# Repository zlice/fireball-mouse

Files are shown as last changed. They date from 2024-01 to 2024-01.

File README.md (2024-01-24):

# Fireball mouse

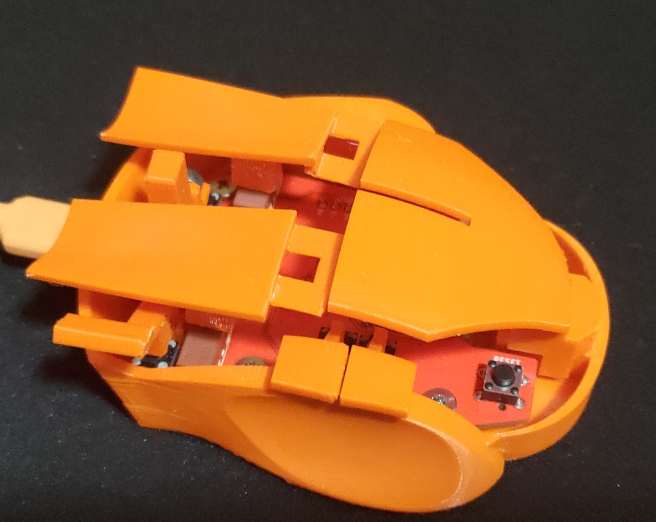
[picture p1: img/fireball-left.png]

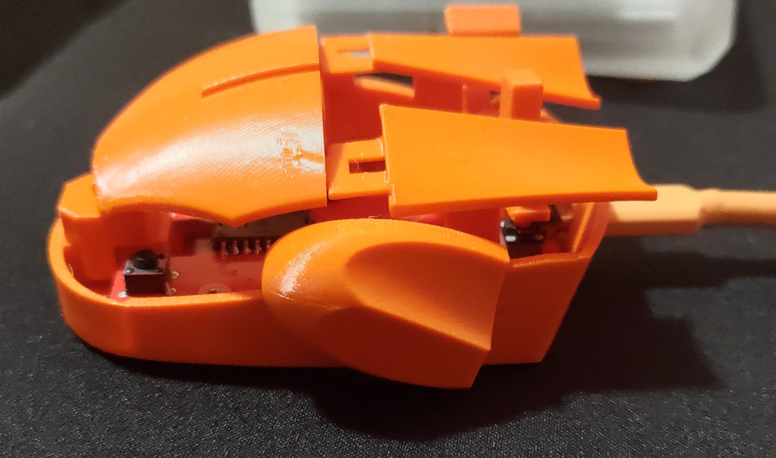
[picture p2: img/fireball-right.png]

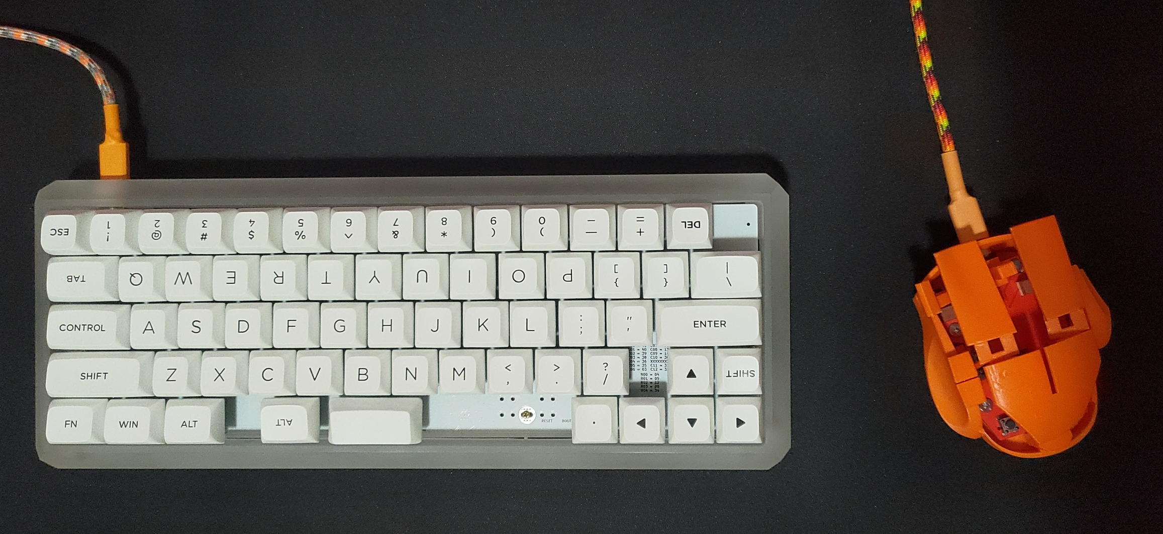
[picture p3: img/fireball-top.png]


Small PMW3360 fingertip mouse with a magnetic hall sensor joystick for scrolling and single 'fire' button for enter.

Designed for Kailh Mute silent switches (the small 6-7mm box ones) and regular sized mouse switches for left/right click (12-13mm x 5-6mm). Bottom is designed for 4 feet with mounting screws near the back middle for the top shell. The top shell is open for minimal hand contact and weight reduction with no 'middleman' shell.

# Building / Parts

### Part List

 - PWM3360 (desolder from donor or grab some off aliexpress)
 - Kailh Quiet Mute Micro Switches (https://www.kailhswitch.com/micro-switches/mouse-micro-switches/quiet-mute-micro-switches.html - aliexpress or elsewhere)
 - USB4085-GF-A (digikey or newark if out of stock on jlcpcb)
 - M3 0.5x4mm screws (PCB and shell mounting - https://www.amazon.com/gp/product/B0C1SGKGWZ)
 - M3 16mm socket screws (for joystick mount - https://www.amazon.com/gp/product/B07PZ3XXPF)
 - N50 magnets 4x1mm cylinder (aliexpress, alibaba, kj magnets)
 - ABS or PC+PBT 3D printing filament (PushPlastic PBT is what I used for my final version. Spool is not compatible with Bambu AMS btw :])
 - Huano Yellow Dot switches (aliexpress, almost linear if not directly 90 degrees of force - optional)
 - TS02-66-50-BK-160-SCR-D (digikey or newark, small 6mm switch for reset/boot - optional)

### Building

May need tweaking for every printer and filament combo. The bambu project in the [stl](./stl) directory should give the orientations and settings that I used to print.

**general print guide**

 - 0.16mm layer height
 - print bottom separate
 - print top separate
 - print small pieces and side clicks together
 - print left/right clicks together
 - 33mm/s outer shell and overhangs
 - support on the the right finger grip
 - support on the thumb, USB and bottom+top screw mounts (auto worked for these)
 - 6 bottom layers for the bottom
 - rotations for the fire/flip, joystick and clicks are important! (joystick will likely break from screw force if in wrong orientation)

**cleanup**

 - bottom screw mount supports can be punctured and twisted out
 - bottom left thumb overhang needs sanding after support is removed
 - left/right click contacts can be sanded, washed, and electrical taped. But click contact can be very finicky (especially with 'huano yellow dot' switches, I eventually gave up and opted to use the raw plastic). This was the hardest part of 'feel' to get right. Contacts may need moved left/right if you use a 12mm omron style switch vs a kailh square switch.
 - side (forward/backward) clicks support can be a bit messy if you wait for it to cool. Removing supports while warm was easier for me in general but should be done here since the part is small and is less likely to warp or deform while still warm.
 - fire button, side clicks and joystick mount are press fit: print smaller test fits before or you'll have to rig some electrical tape for loose fits, or sand (or break) parts on tight fits.
 - magnetic joystick will need tape over the USB connector to make sure it doesn't contact it. The hall sensor routes **under** the joystick faces **away** from the joystick magnets. Technically the wrong direction, but it works great for me. Another sensor can be placed on the side but is best suited in a similar location on the other side of the joystick. See [ideal locations here](./img/halls.png). The code for the joystick/scroll-stick has been updated to read 10 times and use a +- margin to auto-adjust values for scroll up+down. Logic or values may need changed if the magnets are in different polarity or the sensors are positioned differently (reading different ranges).
 - magnets may need test fits depending on print tolerances. Mine were snug and required no glue to stay in place which is perfect. Make sure they are centered and in the right positions (north/south).
 - if your joystick is squeaky or doesn't move smoothly, sanding the inside with the screw's threads may help. Sanding the edges of the bottom or where parts may rub can help also.
 - tightening PCB mounts should be done evenly and just enough to work with everything else
 - tightening top mounts should be done evenly and just enough to work with clicks, every mm counts for feel here

The PCB will likely not line up 100% !!! Tolerances can vary and you are not always going to get the exact same thing if you don't pay for high tolerances.

Be sure to test fit anyway because anything may be off slightly and it could matter!

# QMK

### Setup

Copy **this** project's qmk `fireball` directory to **qmk_firmware**'s `ploopy` directory.

```sh
git clone https://github.com/qmk/qmk_firmware.git

cp -r qmk/keyboards/ploopyco/fireball qmk_firmware/keyboards/ploopyco/
```

### Compile

In `qmk_firmware`

```sh
qmk compile -kb ploopyco/fireball -km default
```

### Flash

The first time you connect the RP2040 it should be empty and go into boot mode. Once flashed, pressing 'forward' while connecting to USB will enter boot mode, reset/boot buttons may help with a reconnect and boot if needed.

Mount the RP2040 and copy `qmk_firmware/.build/ploopyco_fireball_default.uf2` to the RP2040.

```sh
sudo mount /dev/sda1 /mnt/usb && sudo cp .build/ploopyco_fireball_default.uf2 && sudo umount /mnt/usb
```

# FreeCAD

The finished parts are meshed and provided in the [stl](./stl) directory.

Most of this was copied from my original version. The left and right finger grips were slightly modified but I didn't bother reinventing them because they worked for years great. A lot of confusing FreeCAD methods that you can do one way but not another were used to get make parts. The 'misc' group are left over parts that may break the child parts, test fittings and wires used to sweep/loft/extrude and create cuts and parts.

# KiCAD / jlcpcb

Exporting gerbers/drills is the same as every project I've seen, however for jlcpcb I found multiple tutorials and they all seemed out of date. I used [wokwi's jlcpcb script](https://github.com/wokwi/kicad-jlcpcb-bom-plugin) to make placement files, but still needed to rotate them when setting the PCB assembly up.

- File > Fabcrication outputs > component placement (to /tmp/fireball-components)
- `./kicad_pos_to_cpl.py /tmp/fireball-components/Fireball-top-pos.csv /tmp/fireball-jlcpcb-placement-pos.cmp.csv`

The [jlcpcb](./jlcpcb) directory should be a good start to upload for boards.

You may need to replace some parts if they are out of stock. I think I had to use a TexasInstrument converter instead of one in the BOM.

You will have to trim the 4-pin USB header or desolder for it to fit properly in the shell. This is more for a backup or if you do not want to use a USB-C connector and want a straight wire from mouse to the PC USB. If you do not want a raw cable connection, I would remove it from BOM or PCB before exporting.

# Improvements

- PMW3360 bottom mount is slightly off for me and could be moved/centered better.
- The extra PMW3360 mount square groove in the middle is probably useless and could be removed.
- Thumb groove could be extended up a bit at a 45 degree angle. Your thumb can touch the 'back' button since you are not always flat. I don't accidentally press it and it is not that noticeable or bothersome, but it could be something to look at.
- Hall sensor placement could be better. If the PCB is redone, it may be better to put 2 sensors on the side or directly in front+behind the joystick if possible.
- Fire/flip/enter and joystick may feel better if a bit taller. Left/Right clicks ended up being higher than expected.
- Left/Right click feel is more precise to adjust than I expected. Part of this is due to the light weight top and back mounting. The double prong mounts that commercial mice use help prevent rocking side-to-side which created a very uneven, unpredictable and bad click feel. If I try again it may be ideal to mount clicks directly under where they connect somehow, or at least separately.
- Add capacitors to hall sensor outputs to smooth out noise

# Shoutouts

- Jfedor for the PCB - https://github.com/jfedor2/rp2040-pmw3360
- QMK for the software/firmware and helpful community
- wokwi for the placement script - https://github.com/wokwi/kicad-jlcpcb-bom-plugin

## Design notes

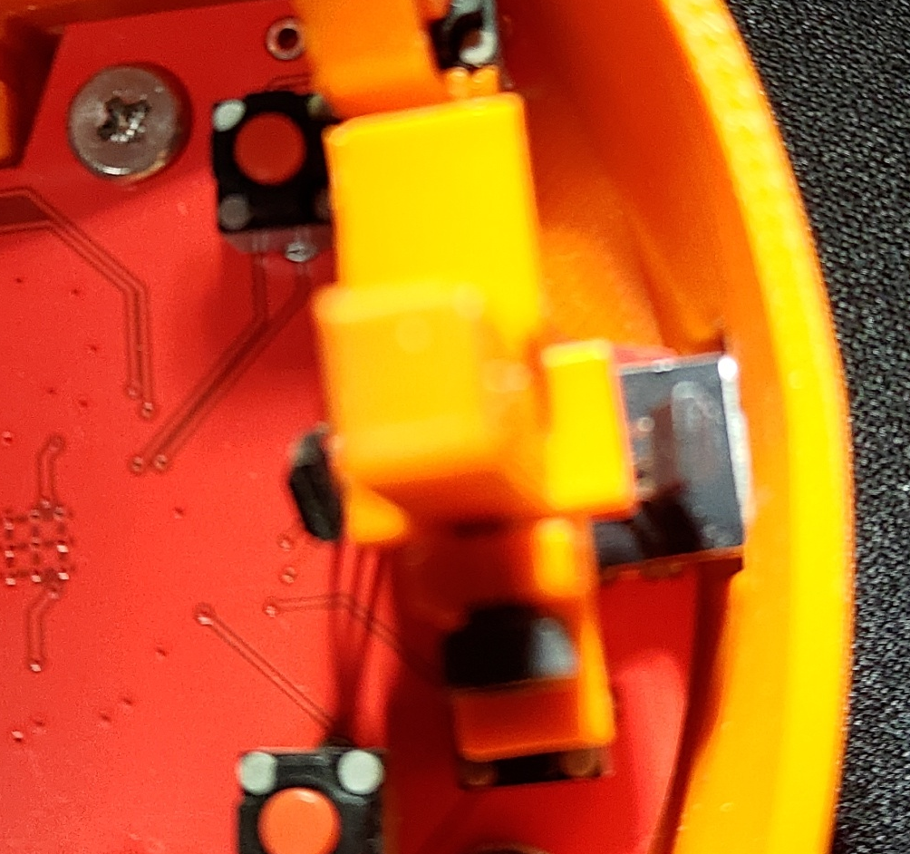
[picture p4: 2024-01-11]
img/halls.png

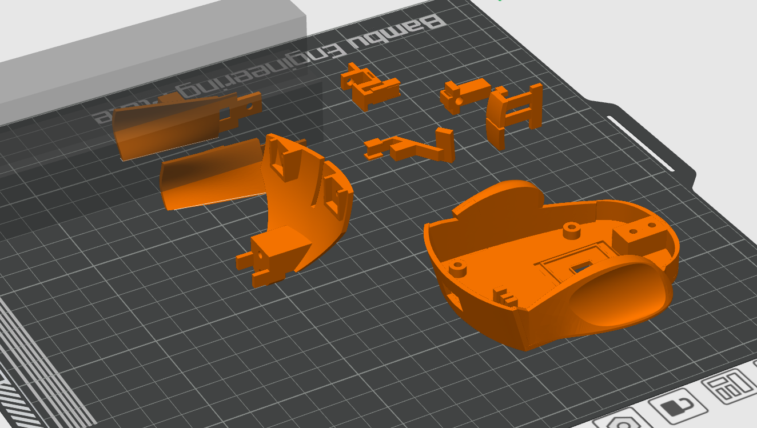
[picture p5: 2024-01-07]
stl/plate1.png

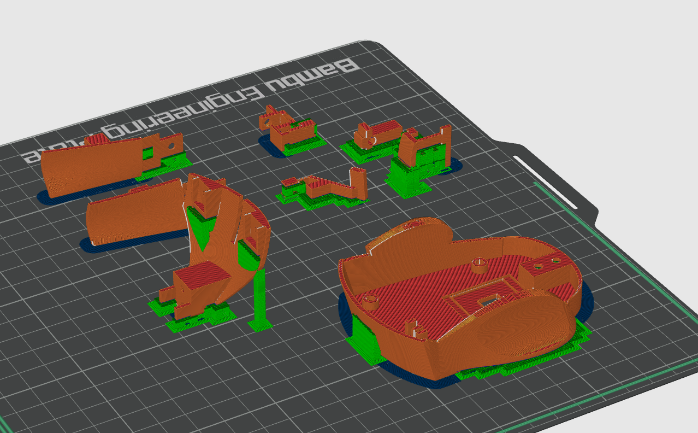
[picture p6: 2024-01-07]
stl/plate2.png

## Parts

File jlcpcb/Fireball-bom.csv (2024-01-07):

Id | Designator | Footprint | Quantity | Designation | Supplier and ref
1 | C18,C19 | C_0402_1005Metric | 2 | 30p | C1570
2 | C17,C2,C8,C6,C5,C7,C4,C1,C3,C9 | C_0402_1005Metric | 10 | 100n | C1525
3 | R6,R7 | R_0402_1005Metric | 2 | 1k | C11702
4 | R5,R2 | R_0402_1005Metric | 2 | 10k | C25744
5 | U3 | RP2040-QFN-56 | 1 | RP2040 | C2040
6 | Y1 | Crystal_SMD_3225-4Pin_3.2x2.5mm | 1 | Crystal_GND24 | C9002
7 | J1 | PinHeader_1x04_P2.54mm_Vertical | 1 | Conn_01x04
8 | C14 | C_0402_1005Metric | 1 | 4.7u | C23733
9 | C10,C16,C15,C13 | C_0402_1005Metric | 4 | 1u | C52923
10 | R4,R3 | R_0402_1005Metric | 2 | 27
11 | U4 | SOT-23-5 | 1 | TLV73333PDBV | C134139
12 | R1 | R_0402_1005Metric | 1 | 39 | C25110
13 | U5 | SOIC-8_5.23x5.23mm_P1.27mm | 1 | W25Q128JVS | C97521
14 | C12 | C_0603_1608Metric | 1 | 1u | C15849
15 | C11 | C_0603_1608Metric | 1 | 0.1u | C14663
16 | U1 | SOT-23-5 | 1 | TCR2EF19

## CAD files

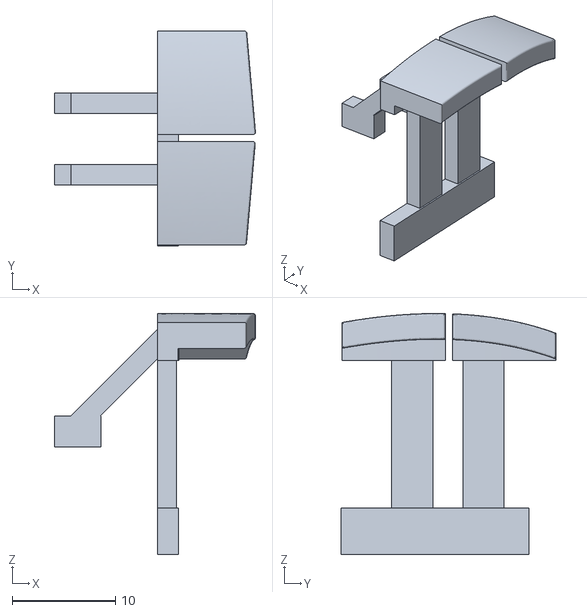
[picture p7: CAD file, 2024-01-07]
stl/side-clk.stl
19.5 x 20.8 x 23.3

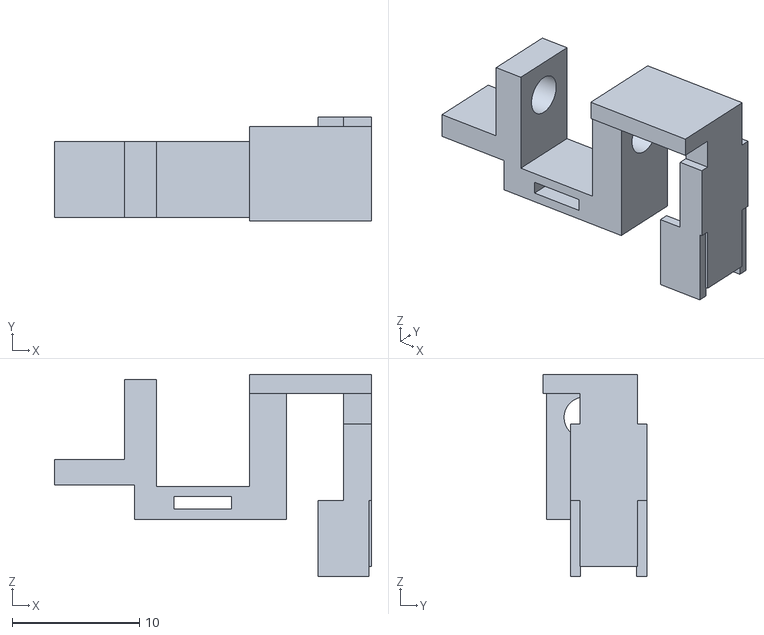
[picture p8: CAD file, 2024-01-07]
stl/js-bot.stl
24.9 x 8.15 x 15.9

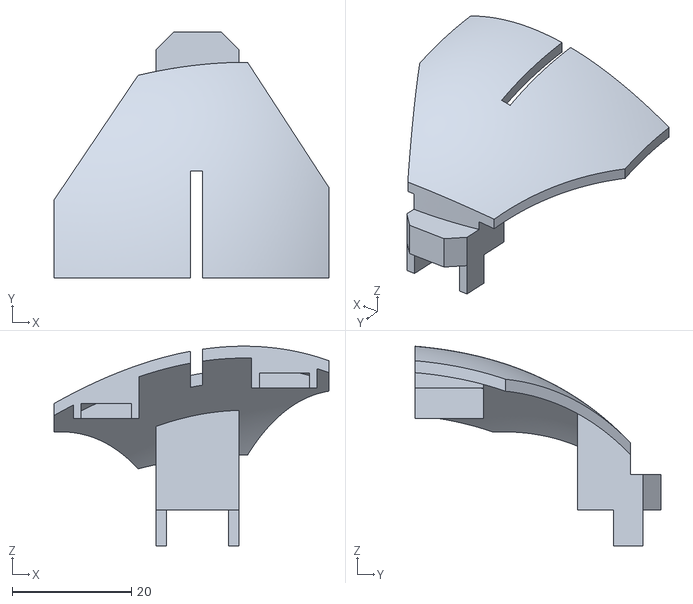
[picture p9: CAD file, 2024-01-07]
stl/top.stl
46.2 x 41.3 x 33.5

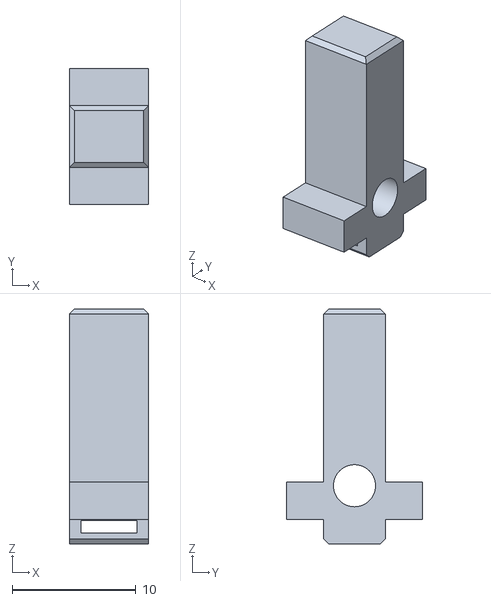
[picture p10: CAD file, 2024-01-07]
stl/js-top.stl
6.40 x 11.0 x 19.0

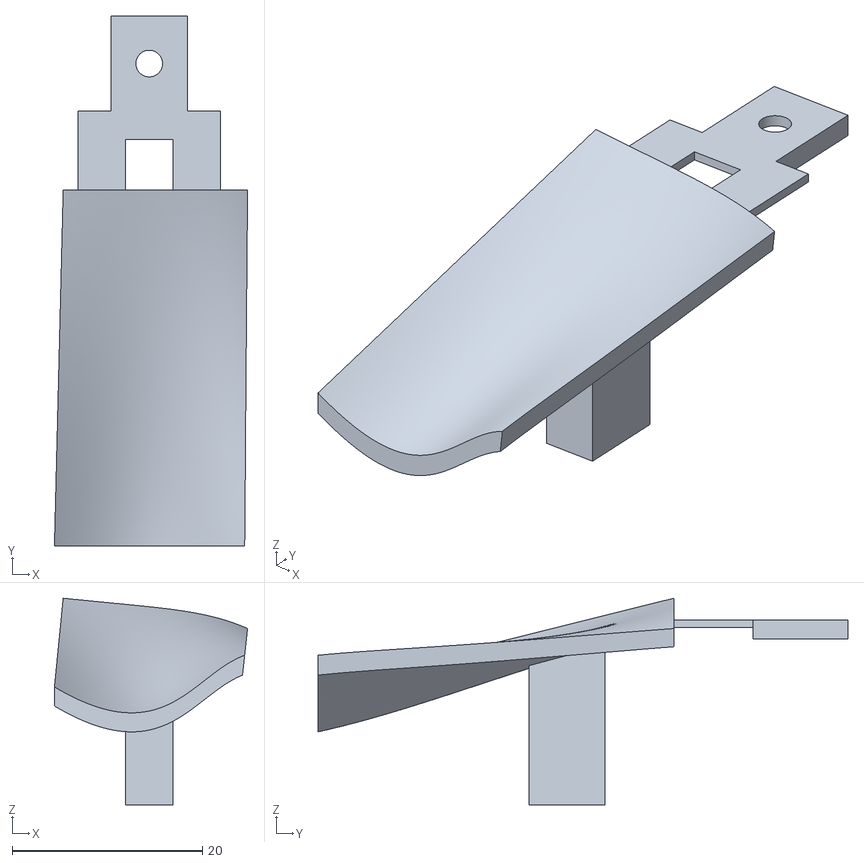
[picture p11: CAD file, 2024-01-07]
stl/lclk.stl
20.3 x 55.7 x 21.7

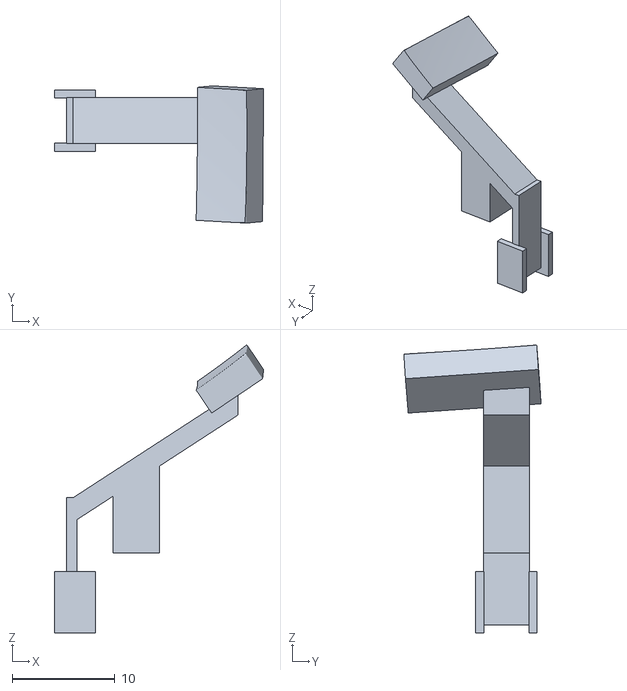
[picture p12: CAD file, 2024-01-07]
stl/flip.stl
20.4 x 13.4 x 28.1

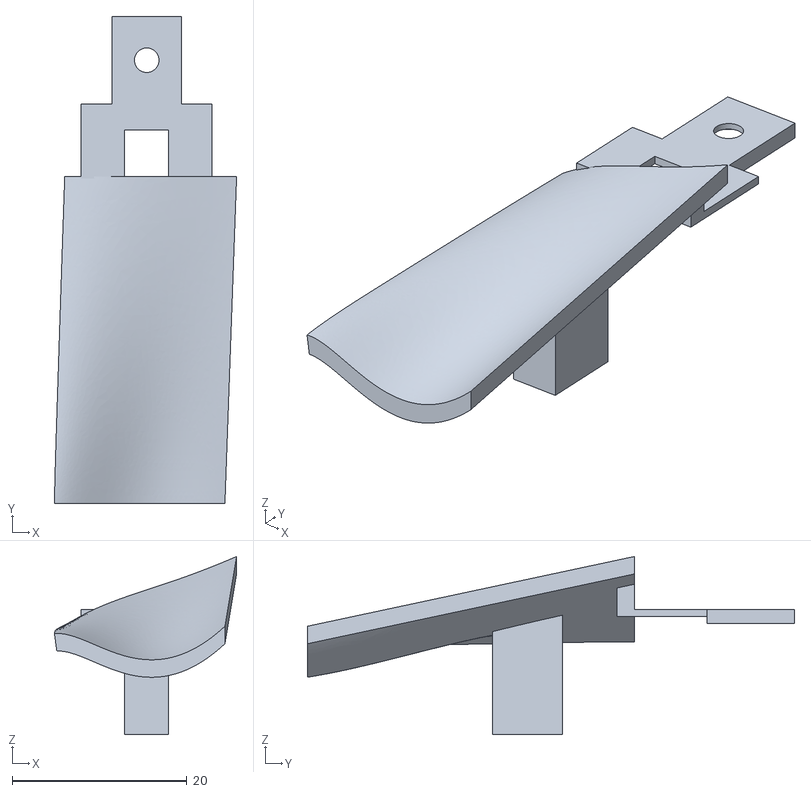
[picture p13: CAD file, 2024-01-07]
stl/rclk.stl
20.8 x 55.7 x 20.4

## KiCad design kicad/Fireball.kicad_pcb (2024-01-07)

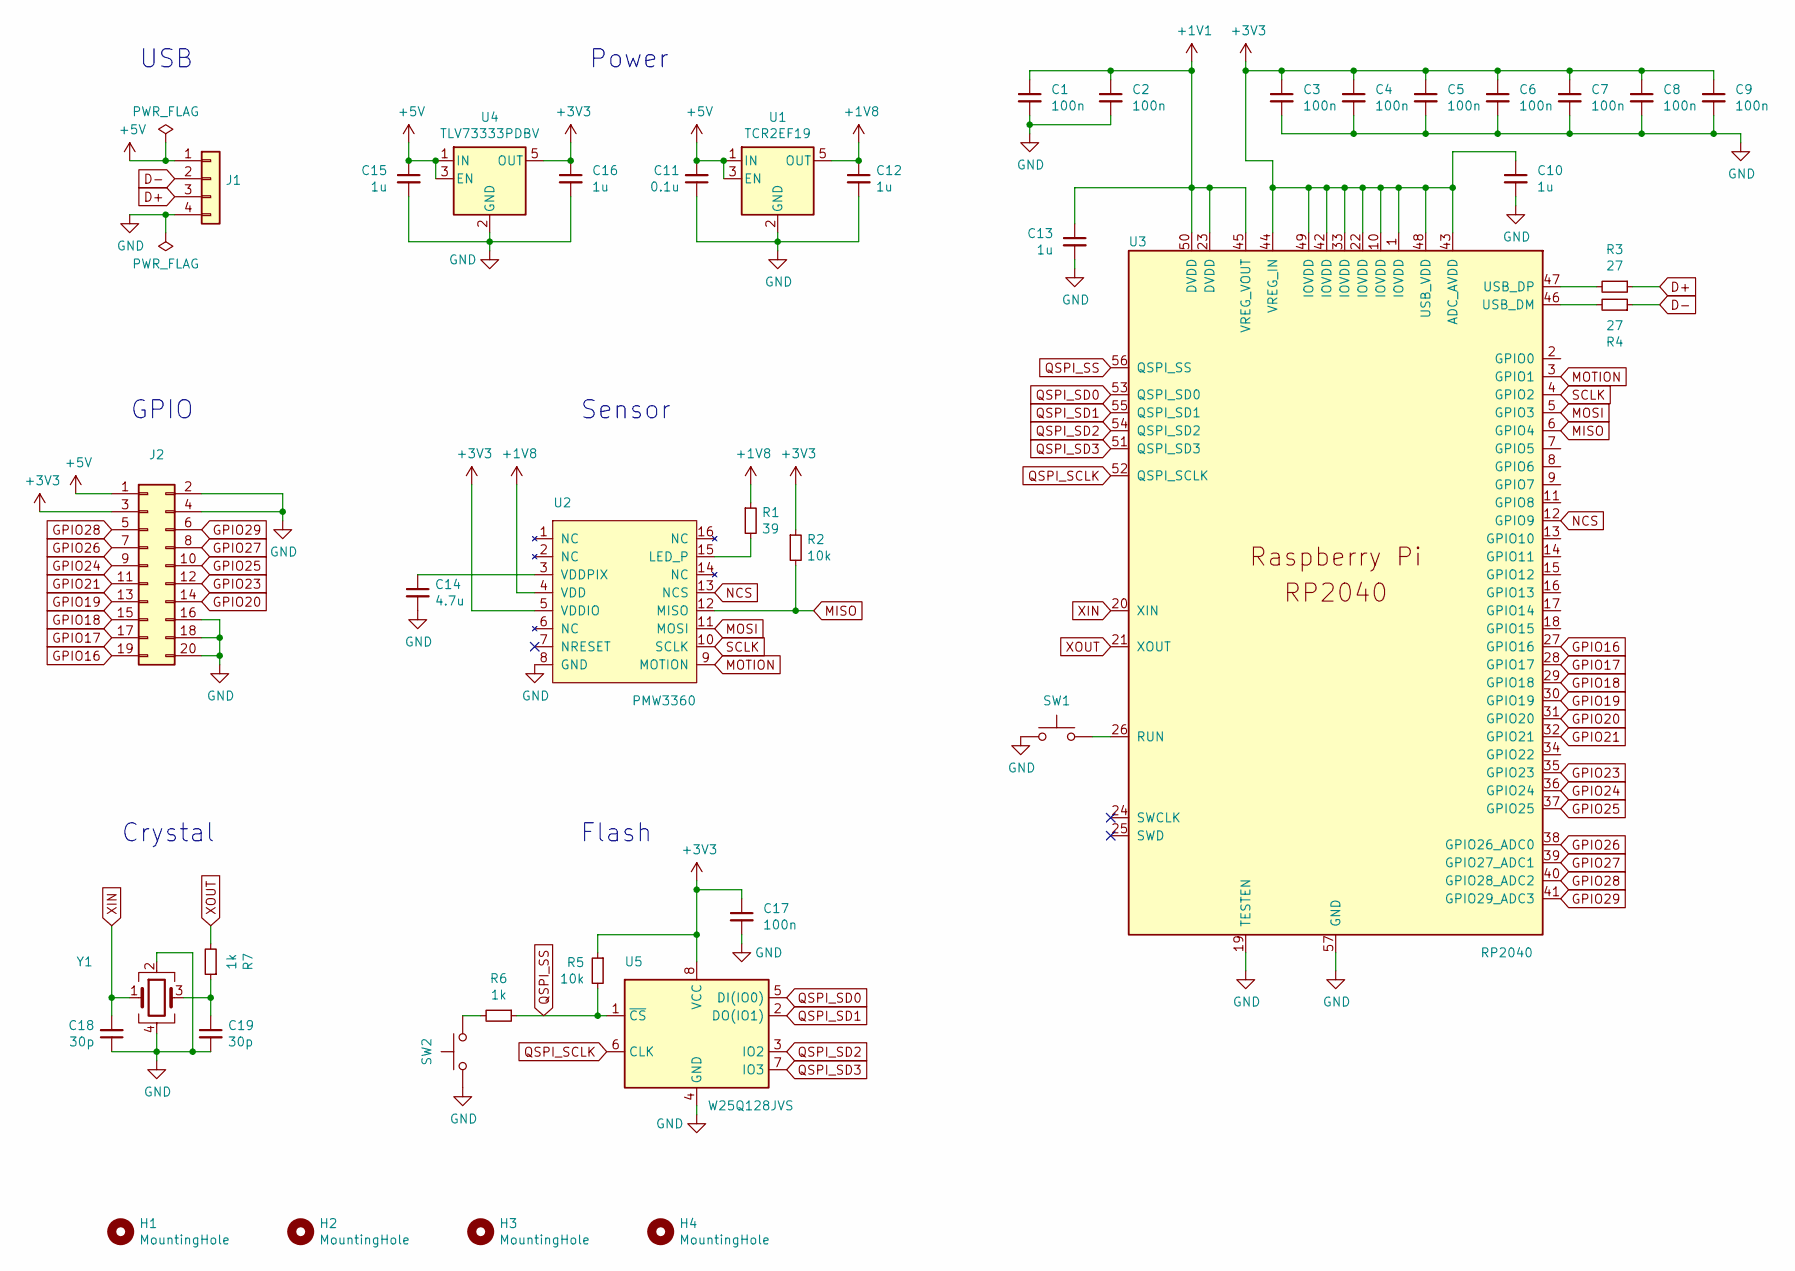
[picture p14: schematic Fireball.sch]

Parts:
C1, C2, C3, C4, C5, C6, C7, C8, C9, C17: 100n; C_0402_1005Metric; LCSC C1525
C10, C13, C15, C16: 1u; C_0402_1005Metric; LCSC C52923
C11: 0.1u; C_0603_1608Metric; LCSC C14663
C12: 1u; C_0603_1608Metric; LCSC C15849
C14: 4.7u; C_0402_1005Metric; LCSC C23733
C18, C19: 30p; C_0402_1005Metric; LCSC C1570
H1, H2, H3, H4: MountingHole; MountingHole_3.2mm_M3
J1: Conn_01x04; PinHeader_1x04_P2.54mm_Vertical
J2: Conn_02x10_Odd_Even; PinHeader_2x10_P2.54mm_Vertical
R1: 39; R_0402_1005Metric; LCSC C25110
R2, R5: 10k; R_0402_1005Metric; LCSC C25744
R3, R4: 27; R_0402_1005Metric; LCSC C138021
R6, R7: 1k; R_0402_1005Metric; LCSC C11702
SW1, SW2: SW_Push; SW_SPST_Omron_B3FS-100xP; LCSC C271750
U1: TCR2EF19; SOT-23-5; LCSC C146366
U2: PMW3360
U3: RP2040; RP2040-QFN-56; LCSC C2040
U4: TLV73333PDBV; SOT-23-5; LCSC C134139
U5: W25Q128JVS; SOIC-8_5.23x5.23mm_P1.27mm; LCSC C97521
Y1: Crystal_GND24; Crystal_SMD_3225-4Pin_3.2x2.5mm; LCSC C9002

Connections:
+1V1: C1.1, C2.1, C13.1, U3.23 (DVDD), U3.45 (VREG_VOUT), U3.50 (DVDD)
+1V8: C12.1, R1.1, U1.5 (OUT), U2.4 (VDD)
+3V3: C3.1, C4.1, C5.1, C6.1, C7.1, C8.1, C9.1, C10.1, C16.1, C17.1, J2.3, R2.1, R5.1, U2.5 (VDDIO), U3.1 (IOVDD), U3.10 (IOVDD), U3.22 (IOVDD), U3.33 (IOVDD), U3.42 (IOVDD), U3.43 (ADC_AVDD), U3.44 (VREG_IN), U3.48 (USB_VDD), U3.49 (IOVDD), U4.5 (OUT), U5.8 (VCC)
+5V: C11.2, C15.1, J1.1, J2.1, U1.1 (IN), U1.3 (EN), U4.1 (IN), U4.3 (EN); also elsewhere on the board
D+: J1.3, R3.1; also elsewhere on the board
D-: J1.2, R4.1; also elsewhere on the board
GND: C1.2, C2.2, C3.2, C4.2, C5.2, C6.2, C7.2, C8.2, C9.2, C10.2, C11.1, C12.2, C13.2, C14.2, C15.2, C16.2, C17.2, C18.1, C19.2, J1.4, J2.2, J2.4, J2.16, J2.18, J2.20, SW1.1, SW2.1, U1.2 (GND), U2.8 (GND), U3.19 (TESTEN), U3.57 (GND), U4.2 (GND), U5.4 (GND), Y1.2, Y1.4; also elsewhere on the board
GPIO16: J2.19, U3.27 (GPIO16)
GPIO17: J2.17, U3.28 (GPIO17)
GPIO18: J2.15, U3.29 (GPIO18)
GPIO19: J2.13, U3.30 (GPIO19)
GPIO20: J2.14, U3.31 (GPIO20)
GPIO21: J2.11, U3.32 (GPIO21)
GPIO23: J2.12, U3.35 (GPIO23)
GPIO24: J2.9, U3.36 (GPIO24)
GPIO25: J2.10, U3.37 (GPIO25)
GPIO26: J2.7, U3.38 (GPIO26_ADC0)
GPIO27: J2.8, U3.39 (GPIO27_ADC1)
GPIO28: J2.5, U3.40 (GPIO28_ADC2)
GPIO29: J2.6, U3.41 (GPIO29_ADC3)
MISO: R2.2, U2.12 (MISO), U3.6 (GPIO4)
MOSI: U2.11 (MOSI), U3.5 (GPIO3)
MOTION: U2.9 (MOTION), U3.3 (GPIO1)
NCS: U2.13 (NCS), U3.12 (GPIO9)
unnamed: C14.1, U2.3 (VDDPIX)
unnamed: C19.1, R7.1, Y1.3
unnamed: R1.2, U2.15 (LED_P)
unnamed: R3.2, U3.47 (USB_DP)
unnamed: R4.2, U3.46 (USB_DM)
unnamed: R6.2, SW2.2
unnamed: SW1.2, U3.26 (RUN)
QSPI_SCLK: U3.52 (QSPI_SCLK), U5.6 (CLK)
QSPI_SD0: U3.53 (QSPI_SD0), U5.5 (DI(IO0))
QSPI_SD1: U3.55 (QSPI_SD1), U5.2 (DO(IO1))
QSPI_SD2: U3.54 (QSPI_SD2), U5.3 (IO2)
QSPI_SD3: U3.51 (QSPI_SD3), U5.7 (IO3)
QSPI_SS: R5.2, R6.1, U3.56 (QSPI_SS), U5.1 (~CS)
SCLK: U2.10 (SCLK), U3.4 (GPIO2)
XIN: C18.2, U3.20 (XIN), Y1.1
XOUT: R7.2, U3.21 (XOUT)

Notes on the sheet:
Crystal
Power
USB
Flash
GPIO
Sensor

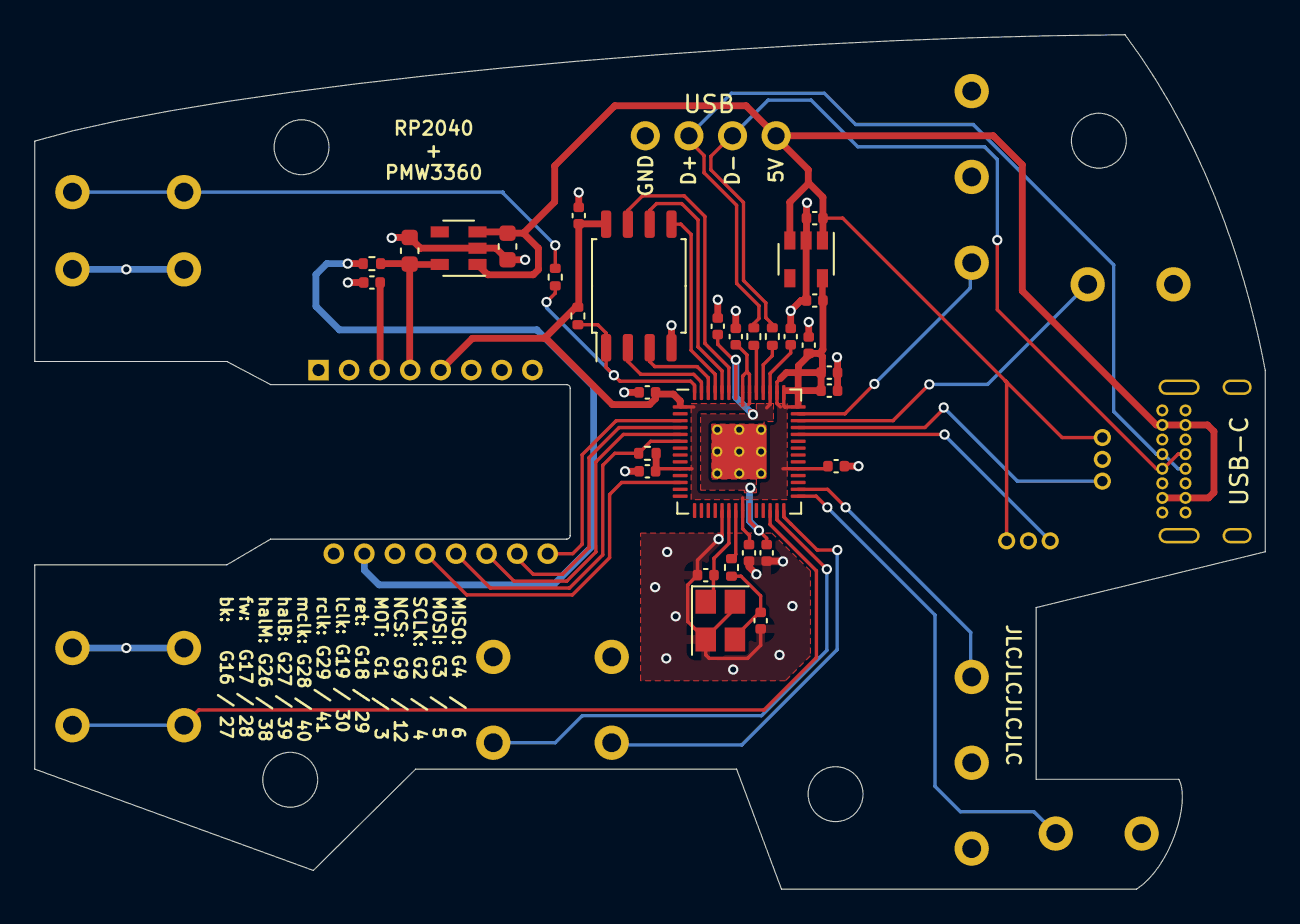
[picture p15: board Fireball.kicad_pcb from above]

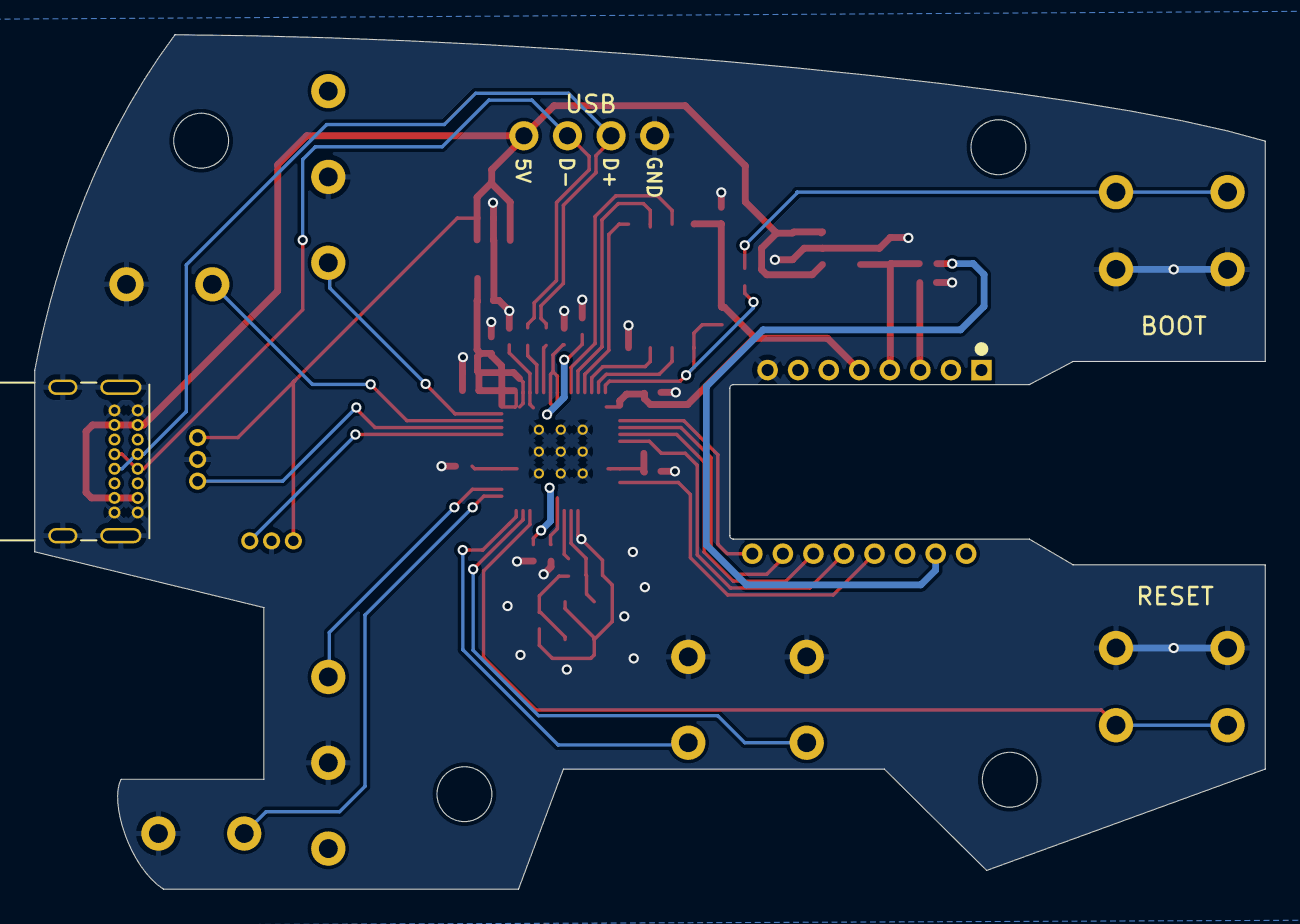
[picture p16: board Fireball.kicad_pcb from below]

Board: 2 copper layers, 71.7 x 49.8 mm, 38 parts (2 on the bottom side), 25 nets.

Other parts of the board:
USB-C: USB_C_Receptacle_GCT_USB4085

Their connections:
+5V: USB-C.A4, USB-C.A9, USB-C.B4, USB-C.B9; also elsewhere on the board
D+: USB-C.A6, USB-C.B6; also elsewhere on the board
D-: USB-C.A7, USB-C.B7; also elsewhere on the board
GND: USB-C.A1, USB-C.A12, USB-C.B1, USB-C.B12, USB-C.S1; also elsewhere on the board

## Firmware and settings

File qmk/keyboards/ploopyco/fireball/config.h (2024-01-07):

/* Copyright 2020 Christopher Courtney, aka Drashna Jael're  (@drashna) <drashna@live.com>
 * Copyright 2019 Sunjun Kim
 * Copyright 2020 Ploopy Corporation
 *
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
 * You should have received a copy of the GNU General Public License
 * along with this program.  If not, see <http://www.gnu.org/licenses/>.
 */

#pragma once

#define ADC_PIN GP26

/* Debounce reduces chatter (unintended double-presses) - set 0 if debouncing is not needed */
#define DEBOUNCE 5

/* Much more so than a keyboard, speed matters for a mouse. So we'll go for as high
   a polling rate as possible. */
#define USB_POLLING_INTERVAL_MS 1
#define USB_MAX_POWER_CONSUMPTION 100

/* define if matrix has ghost (lacks anti-ghosting diodes) */
//#define MATRIX_HAS_GHOST

/* Bootmagic Lite key configuration */
// already in info.json - use 'forward' on boot to reflash
//#define BOOTMAGIC_LITE_ROW 0
//#define BOOTMAGIC_LITE_COLUMN 4

/* PMW3360 Settings */
// CS is SS
#define PMW33XX_CS_PIN GP9

// modifiable - defaults 0x02 - in mm
//#define PMW33XX_LIFTOFF_DISTANCE 0x05
//#define PMW33XX_LIFTOFF_DISTANCE 0x03
// 0x00
// #ROTATIONAL_TRANSFORM_ANGLE 0x00

/*
MISO: G4  /  6
MOSI: G3  /  5
SCLK: G2  /  4
NCS:  G9  / 12
MOT:  G1  /  3 - unused, over SPI iirc
ret:  G18 / 29
lclk: G19 / 30
rclk: G29 / 41
mclk: G28 / 40
halB: G27 / 39 - what i used
halM: G26 / 38 - only good for single direction
fw:   G17 / 28
bk:   G16 / 27
*/

#define SPI_SCK_PIN GP2
#define SPI_MOSI_PIN GP3
#define SPI_MISO_PIN GP4

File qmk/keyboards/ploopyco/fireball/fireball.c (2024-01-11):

/* Copyright 2024 zlice
 * Copyright 2020 Christopher Courtney, aka Drashna Jael're  (@drashna) <drashna@live.com>
 * Copyright 2019 Sunjun Kim
 * Copyright 2020 Ploopy Corporation
 *
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
 * You should have received a copy of the GNU General Public License
 * along with this program.  If not, see <http://www.gnu.org/licenses/>.
 */

#include QMK_KEYBOARD_H

// hall sensor pins
#define HAL1 GP26 // unused - only works well for single direction
#define HAL2 GP27 // good for both directions
//#define MAG_UP 770 // up - js magnet towards hand / stick forward to usb
//#define MAG_DN 770 // down - js magnet towards usb / stick back to hand

#ifndef OPT_DEBOUNCE
#    define OPT_DEBOUNCE 25       // (ms) Time between scroll events - orig 5
#    define OPT_DEBOUNCE_FAST 10  // (ms) Time between scroll events - orig 5
#endif
#ifndef SCROLL_BUTT_DEBOUNCE
#    define SCROLL_BUTT_DEBOUNCE 100  // (ms) Time between scroll events
#endif
#ifndef OPT_THRES
#    define OPT_THRES 150  // (0-1024) Threshold for actication
#endif
#ifndef OPT_SCALE
#    define OPT_SCALE 1  // Multiplier for wheel
#endif
#ifndef PLOOPY_DPI_OPTIONS
#    define PLOOPY_DPI_OPTIONS { 12000, 12000, 12000 }
#    ifndef PLOOPY_DPI_DEFAULT
#        define PLOOPY_DPI_DEFAULT 1
#    endif
#endif
#ifndef PLOOPY_DPI_DEFAULT
#    define PLOOPY_DPI_DEFAULT 0
#endif

keyboard_config_t keyboard_config;
uint16_t          dpi_array[] = PLOOPY_DPI_OPTIONS;
#define DPI_OPTION_SIZE (sizeof(dpi_array) / sizeof(uint16_t))

// TODO: Implement libinput profiles
// https://wayland.freedesktop.org/libinput/doc/latest/pointer-acceleration.html
// Compile time accel selection
// Valid options are ACC_NONE, ACC_LINEAR, ACC_CUSTOM, ACC_QUADRATIC

// Trackball State
bool     is_scroll_clicked = false;
uint16_t lastScroll        = 0;      // Previous confirmed wheel event
bool     debug_encoder     = false;

uint16_t lastMidClick      = 0;      // Stops scrollwheel from being read if it was pressed
uint16_t cur_opt_debounce = OPT_DEBOUNCE;
uint16_t scroll_hits = 0; // tracker for 40 25ms intervals = 1sec (1000ms)
#define SCROLL_RAMP 40
// finds a high/lo resting point and sets
#define MAG_MARGIN 5 // offset max MAG_XX values before registering both scrolls
#define UP_MARGIN 10 // offset for registering up scrolls
#define DN_MARGIN 18 // offset for registering down scrolls
uint16_t MAG_UP = 888 ; // up - js magnet towards hand / stick forward to usb
uint16_t MAG_DN = 888 ; // down - js magnet towards usb / stick back to hand

// HALL SENSOR JOYSTICK JS
void process_wheel(void) {

    // proper qmk way to read is with mux
    // unused is an error in qmk
    uint16_t val1 = analogReadPin(HAL1);
    uint16_t val2 = analogReadPin(HAL2);

    // Don't scroll if the middle button is depressed.
    if (is_scroll_clicked) {
#ifndef IGNORE_SCROLL_CLICK
      return;
#endif
    }

    // If the mouse wheel was just released, do not scroll.
    if (timer_elapsed(lastMidClick) < SCROLL_BUTT_DEBOUNCE) {
      return;
    }

    // orig val is 5ms - changed to 25, with 10 after 1 sec (40 25ms hits)
    //                   u16 overflows after hour of scrolling?
    // Limit the number of scrolls per unit time.
    cur_opt_debounce = OPT_DEBOUNCE;
    if (scroll_hits > SCROLL_RAMP) {
      cur_opt_debounce = OPT_DEBOUNCE_FAST;
    }

    if (timer_elapsed(lastScroll) < cur_opt_debounce) {
      return;
    }

    // actual joystick scroll logic
    // debug + CONSOLE need enabled in in rules.mk
    // dances around 740 +-, can hit 73X which is similar to 'down'
    // values vary per sensor, PCB and positioning
    // use this to figure out what works for you
    //uprintf("mag read: %u\n", val2);
    //uprintf("MAG_UP : %u\tMAG_DOWN : %u\n", MAG_UP, MAG_DN);
    //uprintf("val1 : %u\tval2 : %u\n", val1, val2);

    lastScroll = timer_read();
    scroll_hits += 1;

    // dual sensors
    if (val1 < MAG_UP) {
      tap_code(KC_WH_U);
    } else if (val2 < MAG_DN) {
      tap_code(KC_WH_D);
    } else {
      scroll_hits = 0;
    }
    // single sensor
    // if (val2 < MAG_DN) {
    //   tap_code(KC_WH_D);
    // } else if (val2 > MAG_UP) {
    //   tap_code(KC_WH_U);
    // } else {
    //   scroll_hits = 0;
    // }
}

report_mouse_t pointing_device_task_kb(report_mouse_t mouse_report) {
    process_wheel();

    // invert / reverse / upside down sensor
    mouse_report.x = mouse_report.x * -1;
    mouse_report.y = mouse_report.y * -1;

    return pointing_device_task_user(mouse_report);
}

bool process_record_kb(uint16_t keycode, keyrecord_t* record) {
    // Update Timer to prevent accidental scrolls
    if ((record->event.key.col == 1) && (record->event.key.row == 0)) {
        lastMidClick      = timer_read();
        is_scroll_clicked = record->event.pressed;
    }

    if (!process_record_user(keycode, record)) {
        return false;
    }

    if (keycode == DPI_CONFIG && record->event.pressed) {
        keyboard_config.dpi_config = (keyboard_config.dpi_config + 1) % DPI_OPTION_SIZE;
        eeconfig_update_kb(keyboard_config.raw);
        pointing_device_set_cpi(dpi_array[keyboard_config.dpi_config]);
    }

    return true;
}

// Hardware Setup
void keyboard_pre_init_kb(void) {
    // debug_enable  = true;
    // debug_matrix  = true;
    // debug_mouse   = true;
    // debug_encoder = true;

    setPinInput(HAL1);
    setPinInput(HAL2);
    uint16_t hal = 0;
    // more reads (without touching) will find a better 'rest' point
    for (int i = 0 ; i < 12 ; i++) {
      hal = analogReadPin(HAL2);
      if (hal < MAG_DN)
        MAG_DN = hal;
      hal = analogReadPin(HAL1);
      if (hal < MAG_UP)
        MAG_UP = hal;
    }
    MAG_DN -= (DN_MARGIN + MAG_MARGIN);
    MAG_UP -= (UP_MARGIN + MAG_MARGIN);

    /* Ground all output pins connected to ground. This provides additional
     * pathways to ground. If you're messing with this, know this: driving ANY
     * of these pins high will cause a short. On the MCU. Ka-blooey.
     */
#ifdef UNUSABLE_PINS
    const pin_t unused_pins[] = UNUSABLE_PINS;

    for (uint8_t i = 0; i < ARRAY_SIZE(unused_pins); i++) {
        setPinOutput(unused_pins[i]);
        writePinLow(unused_pins[i]);
    }
#endif

    // This is the debug LED.
#if defined(DEBUG_LED_PIN)
    setPinOutput(DEBUG_LED_PIN);
    writePin(DEBUG_LED_PIN, debug_enable);
#endif

    keyboard_pre_init_user();
}

void pointing_device_init_kb(void) {
    pointing_device_set_cpi(dpi_array[keyboard_config.dpi_config]);
}

void eeconfig_init_kb(void) {
    keyboard_config.dpi_config = PLOOPY_DPI_DEFAULT;
    eeconfig_update_kb(keyboard_config.raw);
    eeconfig_init_user();
}

void matrix_init_kb(void) {
    // is safe to just read DPI setting since matrix init
    // comes before pointing device init.
    keyboard_config.raw = eeconfig_read_kb();
    if (keyboard_config.dpi_config > DPI_OPTION_SIZE) {
        eeconfig_init_kb();
    }
    matrix_init_user();
}

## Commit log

2024-01-11 update hall sensors
2024-01-11 reverse primary hall sensor and update code for auto-value on startup
    [fireball.c]
2024-01-24 todo: capacitors for hall sensor noise

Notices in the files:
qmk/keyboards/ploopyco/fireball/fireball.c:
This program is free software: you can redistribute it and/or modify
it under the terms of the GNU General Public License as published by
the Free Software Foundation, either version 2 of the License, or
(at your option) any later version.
